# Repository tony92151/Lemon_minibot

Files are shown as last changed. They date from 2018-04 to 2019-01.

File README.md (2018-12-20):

# Lemon minibot

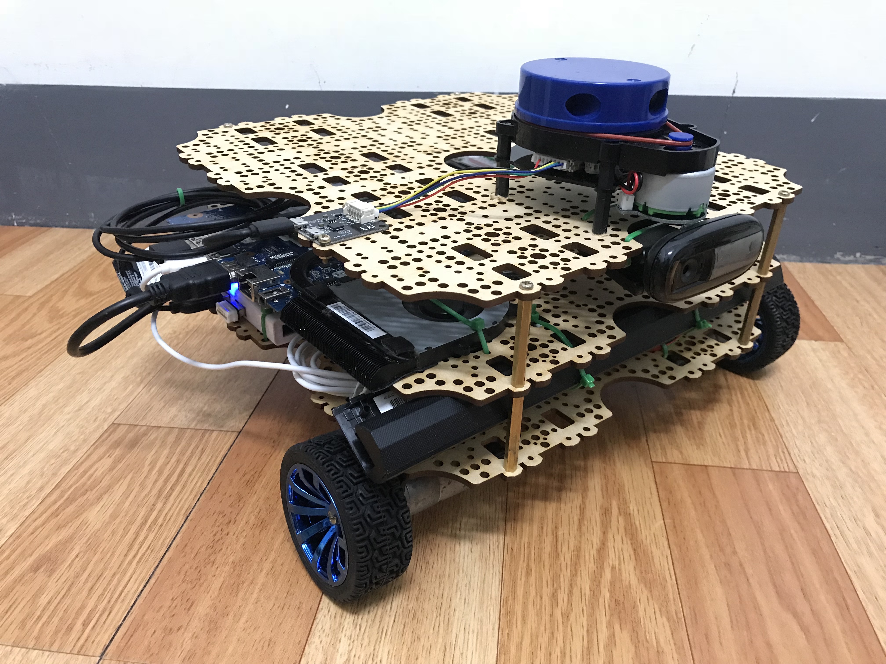
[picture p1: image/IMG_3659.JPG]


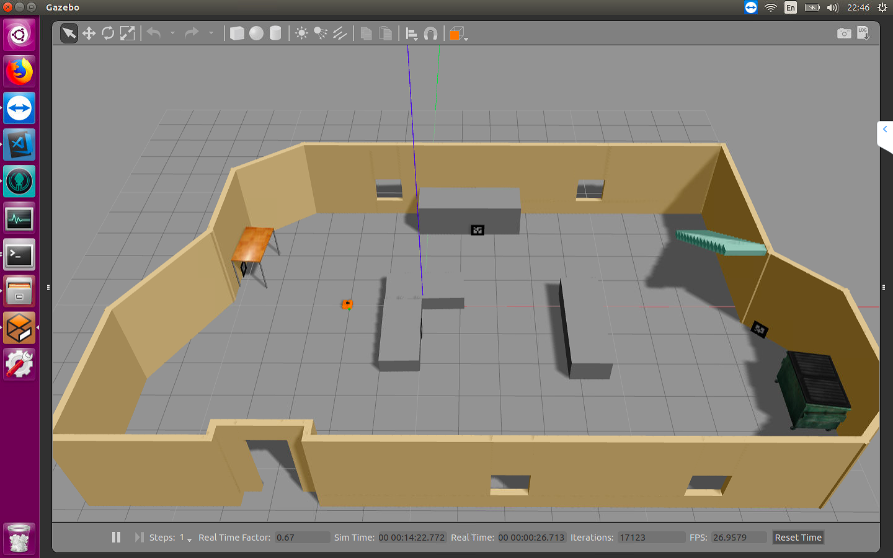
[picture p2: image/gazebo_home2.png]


# Hardware

Raspberry Pi3
(I use the motherboard of lenovo ideapad 100)

YDLidar X4

Arduino mega2560 & motor controller

Motor with A/B encode

14.8v li-po battery

Laser cut frame

# Software

## How to install ROS

Read my medium

https://medium.com/@tony92151/%E5%B0%88%E9%A1%8C%E7%AD%86%E8%A8%98-ros-1-c87bd92b16bc

# How to use

## Clone repositories

1.Clone this repository

> cd catkin_ws/src

> git clone https://github.com/tony92151/Lemon_minibot.git

2.Clone repository for YDLidar X4

> git clone https://github.com/EAIBOT/ydlidar

3.Clone repository for rf2o

> git clone https://github.com/MAPIRlab/rf2o_laser_odometry

4.Clone repository for smach

>git clone https://github.com/ros-visualization/executive_smach_visualization.git

5.instsll dependent

> sudo apt-get install remmina synaptic gimp git ros-kinetic-navigation ros-kinetic-amcl ros-kinetic-slam-gmapping ros-kinetic-mrpt-slam ros-kinetic-mrpt-icp-slam-2d ros-kinetic-robot-localization ros-kinetic-ar-track-alvar -y 

6.Compile all

> cd ..

> catkin_make

## Starup setting

> cd catkin_ws/src/Lemon_minibot/starup/

> sudo chmod +x initenv.sh

then enter your password

>./initenv.sh

## YDLidar X4 starup setting

> roscd ydlidar/starup/

> sudo chmod 777 ./*

> sudo sh initenv.sh

## Add ar-tag models 

> cd

> git clone https://github.com/mikaelarguedas/gazebo_models.git

> cd ar_tags/scripts/

> ./generate_markers_model.py -i ~/Documents/gazebo_models/ar_tags/images -g ~/.gazebo/models -s 80

## Simulation test

> roslaunch turtlebot3_copy turtlebot_world2.launch

If it is first time open gazebo, it will take about 10 min to download models
or you can download manual

See detial here

https://medium.com/@tony92151/%E5%AF%A6%E6%88%B0-ros-gazebo-1-bdb941f184e1

## joystick test (RONEVER SR-012)

> roslaunch joy joy2t.launch

> rostopic echo /car/cmd_vel 

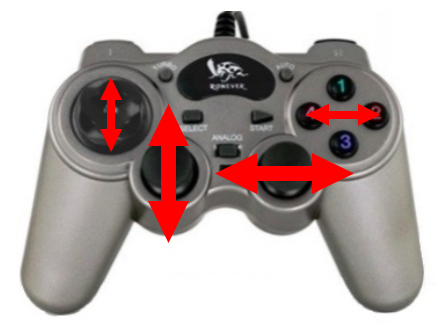
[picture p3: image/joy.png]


### Run gmapping

> roslaunch turtlebot3_copy turtlebot_world2.launch

then gazebo with minibot & home will star

> roslaunch lemon_minibot_detect ar_tag_sim.launch

to save the addres from ar-tag, run tf listener

> rosrun lemon_minibot_core ar_local.py

> roslaunch minibot_simulation simulation_gmapping.launch

to control your robot in gazebo, run keyboard_teleop.py to publish message to control node (/car/cmd_vel)

> rosrun lemon_minibot_control keyboard_teleop.py

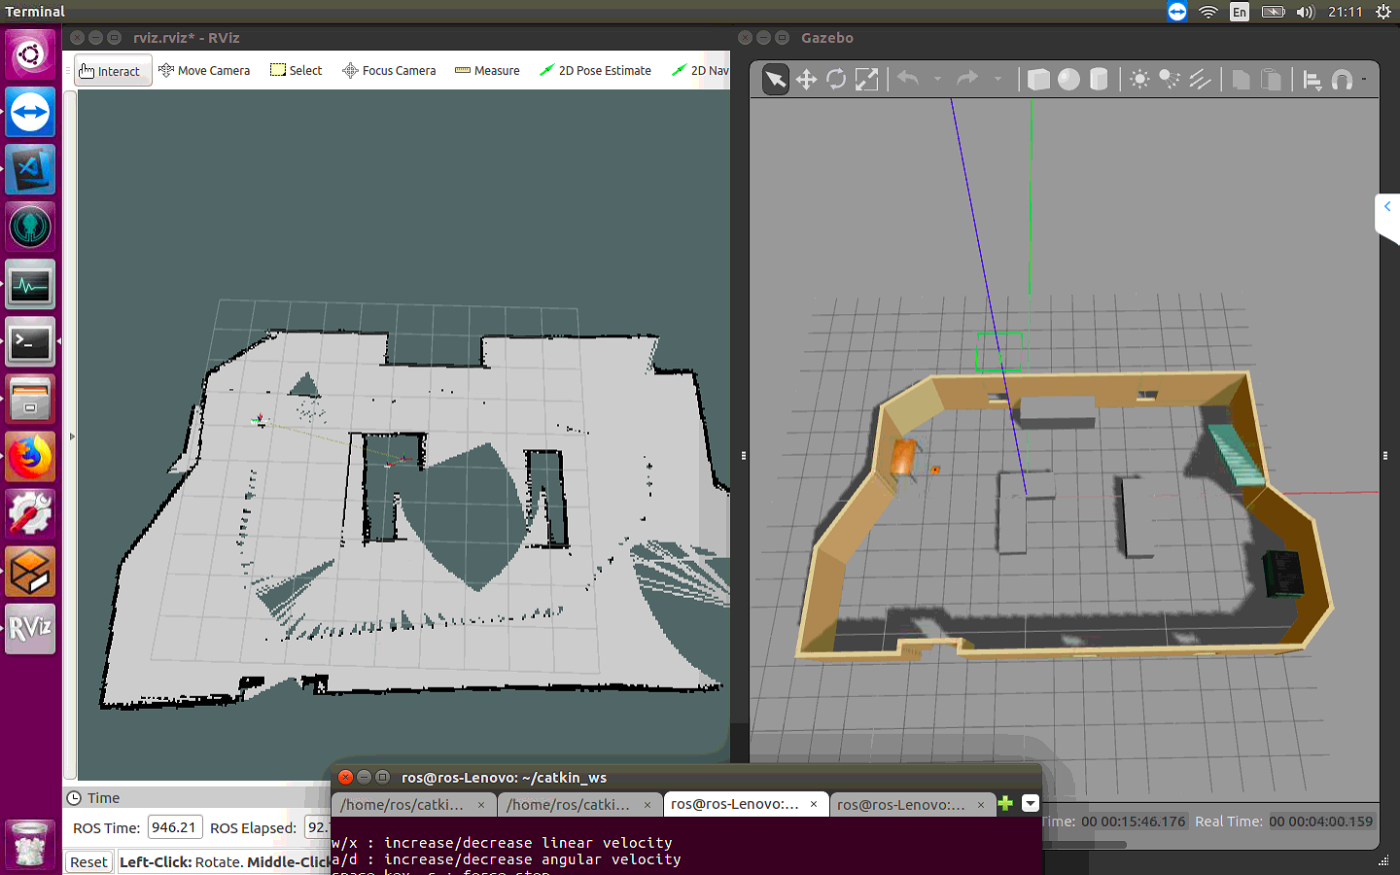
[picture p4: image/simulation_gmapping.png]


When mapping complete, save the map

> rosrun map_server map_saver -f ~/homemap

### run navigation

> roslaunch minibot_simulation simulation_navigation.launch map_file:=$HOME/homemap.yaml

nav goal sender

> roslaunch lemon_minibot_control movebase_seq.launch

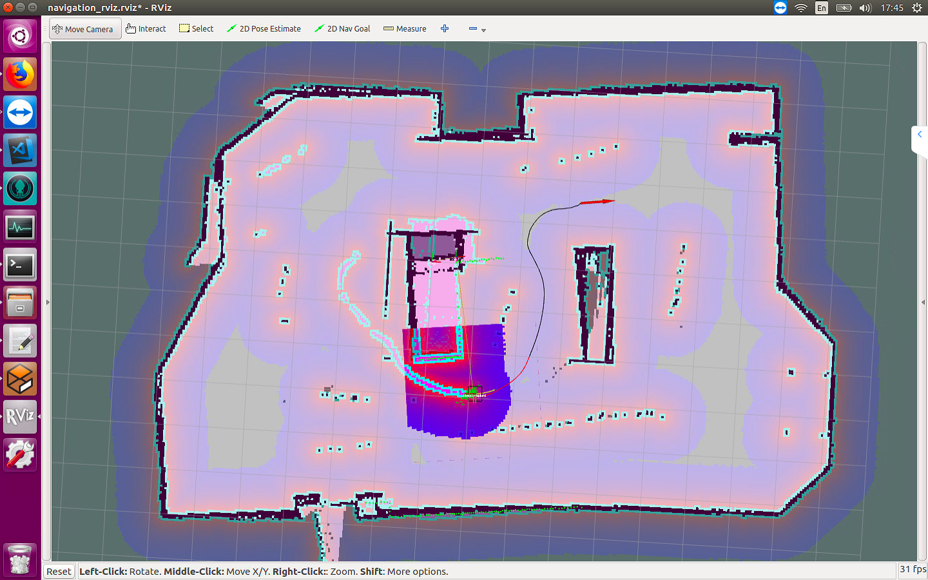
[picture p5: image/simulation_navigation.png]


## Smach viewer 

> rosrun smach_viewer smach_viewer.py

## set up amazom alexa skill

## Use amazon alexa

> rosrun lemon_minibot_core smach3.py

> roscd lemon_minibot_control/scripts/alexa/

> ./ngrok http 5000

and ngrok will give you the address then pastes it to "Alexa skill kit" end point

### install necessary pkg

> sudo apt-get install ngrok-client

> sudo pip install request flask flask-ask requests unidecode

### run web server to connect to amazon alexa skill

> rosrun lemon_minibot_control alexa_skill.py

> roscd lemon_minibot_control/scripts/alexa/

> ./ngrok http 5000

## Demo setup

> roscore

> roslaunch turtlebot3_copy turtlebot_world2.launch

> rosparam load ~/catkin_ws/src/Lemon_minibot/lemon_minibot_core/param/location.yaml

> rosparam load ~/catkin_ws/src/Lemon_minibot/lemon_minibot_core/param/smach.yaml

> rosrun lemon_minibot_core smach3.py

> roscd lemon_minibot_control/scripts/alexa/

> ./ngrok http 5000

> rosrun lemon_minibot_core core_controller.py

# Demo video
(http://www.youtube.com/watch?v=-EDsaaNJGFU "demo")

(http://www.youtube.com/watch?v=rqNOdHbekDU "final")

# Reference

[1]turtlebot3
https://github.com/ROBOTIS-GIT/turtlebot3

[2]gazebo_models
https://github.com/mikaelarguedas/gazebo_models

[3]roslaunch API Usage
http://wiki.ros.org/roslaunch/API%20Usage

[4]Module rosparam in python
http://docs.ros.org/diamondback/api/rosparam/html/

[5]smach Tutorials
http://wiki.ros.org/smach/Tutorials/Getting%20Started

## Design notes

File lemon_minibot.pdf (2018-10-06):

專題研究

# Lemon minibot

# Navigation system robot car

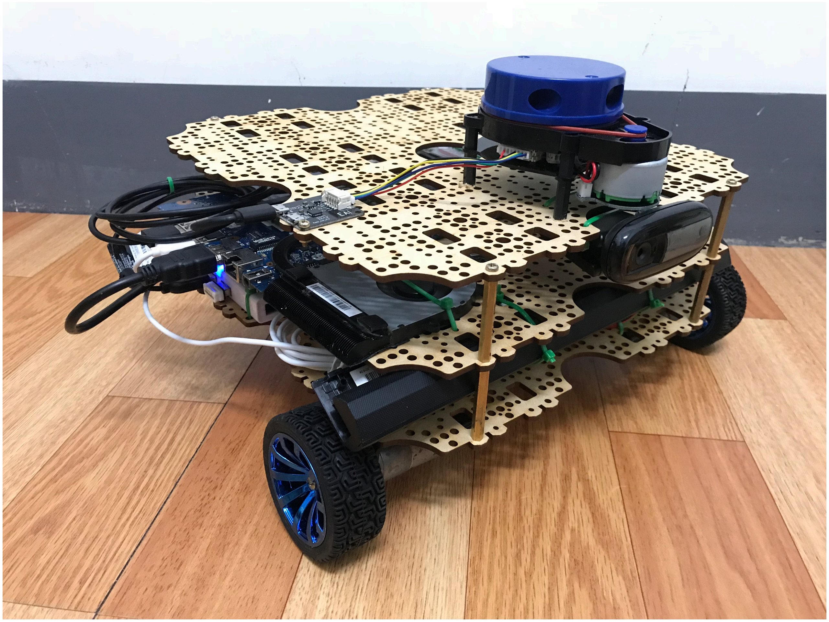
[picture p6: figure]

Authors:Tony Guo

# Abstract

# Content

# Chapter 1 Introduction

# Chapter 2 Hardware

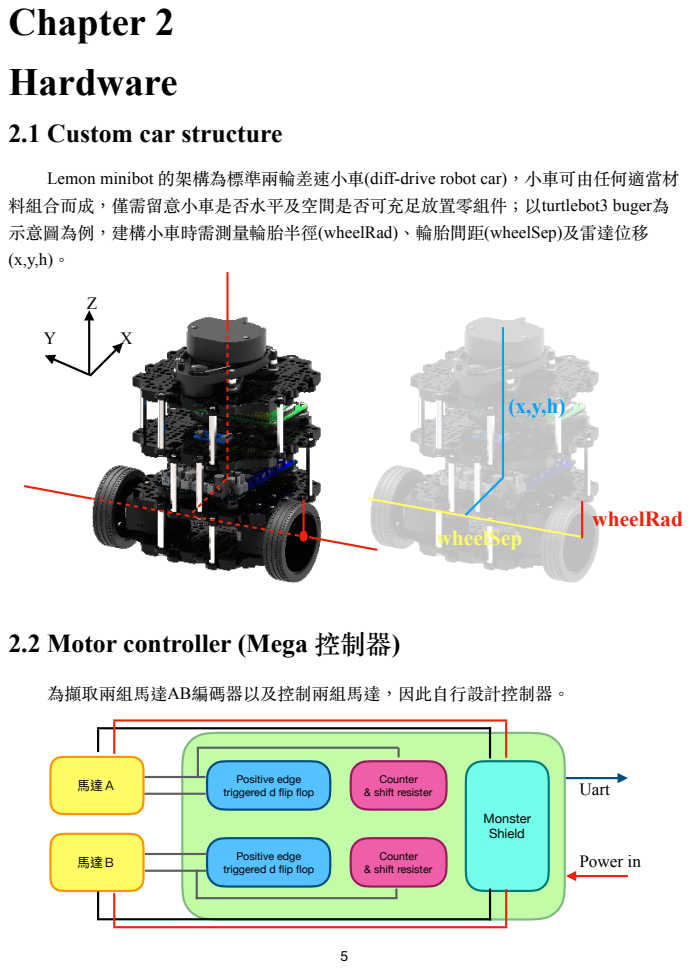
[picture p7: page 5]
wheelSep; wheelRad; ⾺馬達Ａ; ⾺馬達Ｂ; Counter & shift resister; Monster Shield; Uart; Power in

2.1 Custom car structure

Lemon minibot 的架構為標準兩輪差速⼩⾞(diff-drive robot car)，⼩⾞可由任何適當材
料組合⽽成，僅需留意⼩⾞是否⽔平及空間是否可充⾜放置零組件︔以turtlebot3 buger為
⽰意圖為例，建構⼩⾞時需測量輪胎半徑(wheelRad)、輪胎間距(wheelSep)及雷達位移

2.2 Motor controller (Mega 控制器)

為擷取兩組⾺達AB編碼器以及控制兩組⾺達，因此⾃⾏設計控制器。

Positive edge
triggered d flip flop

### 2.2.1 Motor & A/B encoder

擁有AB增量型編碼器的⾺達都有6pin，分別為⾺達正負極、編碼器電源以及AB相輸 出，接下來將說明如何使⽤編碼器訊號測量轉向以及轉速，在這之前也必須先知道⾺達的 PPR (Pulses per rev)值，意味著轉⼀圈會經過幾個脈衝︔再者如果⾺達有經過減速機，則 須將PPR乘上減速比。

Lemon minibot 所使⽤的的編碼器為AB增量型編碼器，編碼器輸出為AB相，如下 圖，A與B之間相位差為90度。

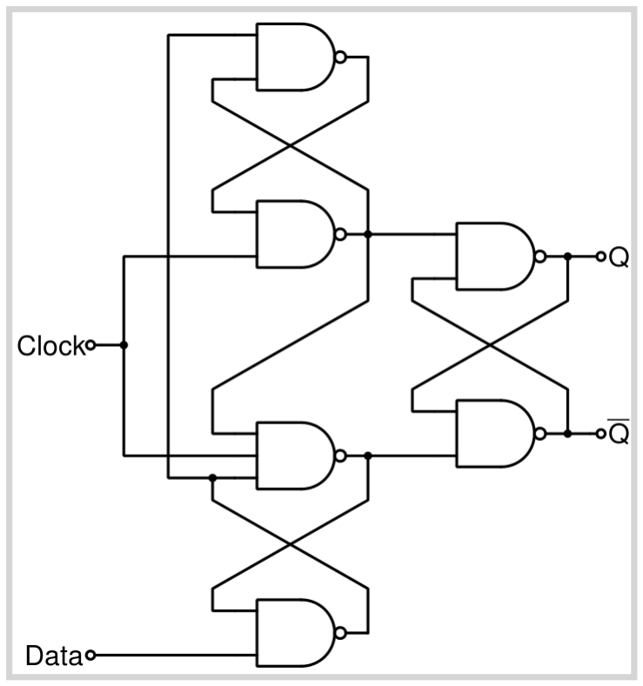
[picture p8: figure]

### 2.2.2 Positive edge triggered d flip flop

正緣觸發D正反器 (positive edge triggered d flip flop)，可以將AB相轉換成單⼀輸出的轉向︔當clock背A 相正緣觸發時會將Q輸出B相的值，⽽依照2.2.1 AB相圖 可知，正反轉會輸出不同的值，並以此作為正反轉訊號。

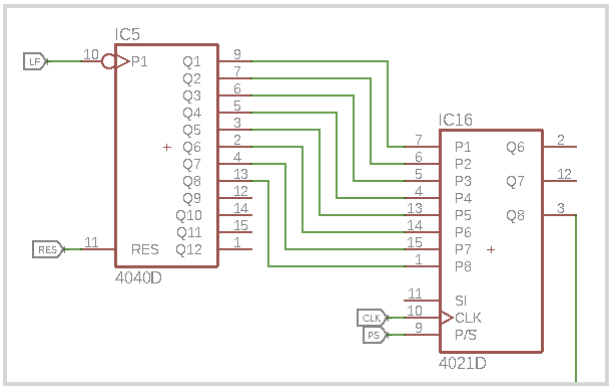
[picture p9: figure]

### 2.2.3 Counter & shift resister

CD4040為12bits計數器 (Counter)， CD4021為8bits的位移暫存器 (Shift
resister)︔解釋期運作原理，將訊號由計數
器的PIN10輸入，輸入脈衝數換成⼆進位
制由Q1~Q12輸出，再經過位移暫存器輸
入至微控器。

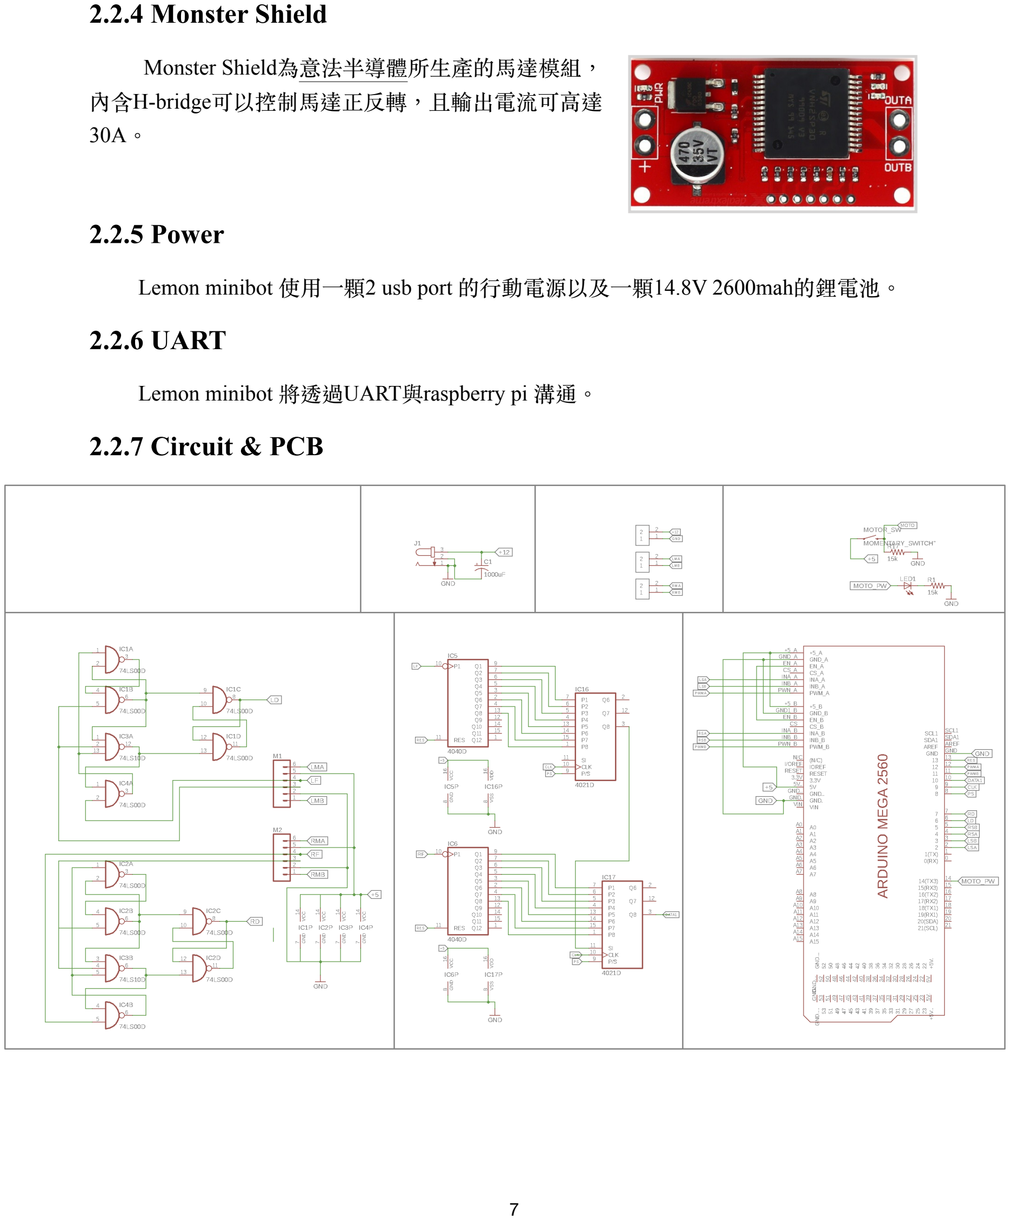
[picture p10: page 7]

### 2.2.4 Monster Shield

Monster Shield為意法半導體所⽣產的⾺達模組， 內含H-bridge可以控制⾺達正反轉，且輸出電流可⾼達
30A。

### 2.2.5 Power

Lemon minibot 使⽤⼀顆2 usb port 的⾏動電源以及⼀顆14.8V 2600mah的鋰電池。

### 2.2.6 UART

Lemon minibot 將透過UART與raspberry pi 溝通。

### 2.2.7 Circuit & PCB

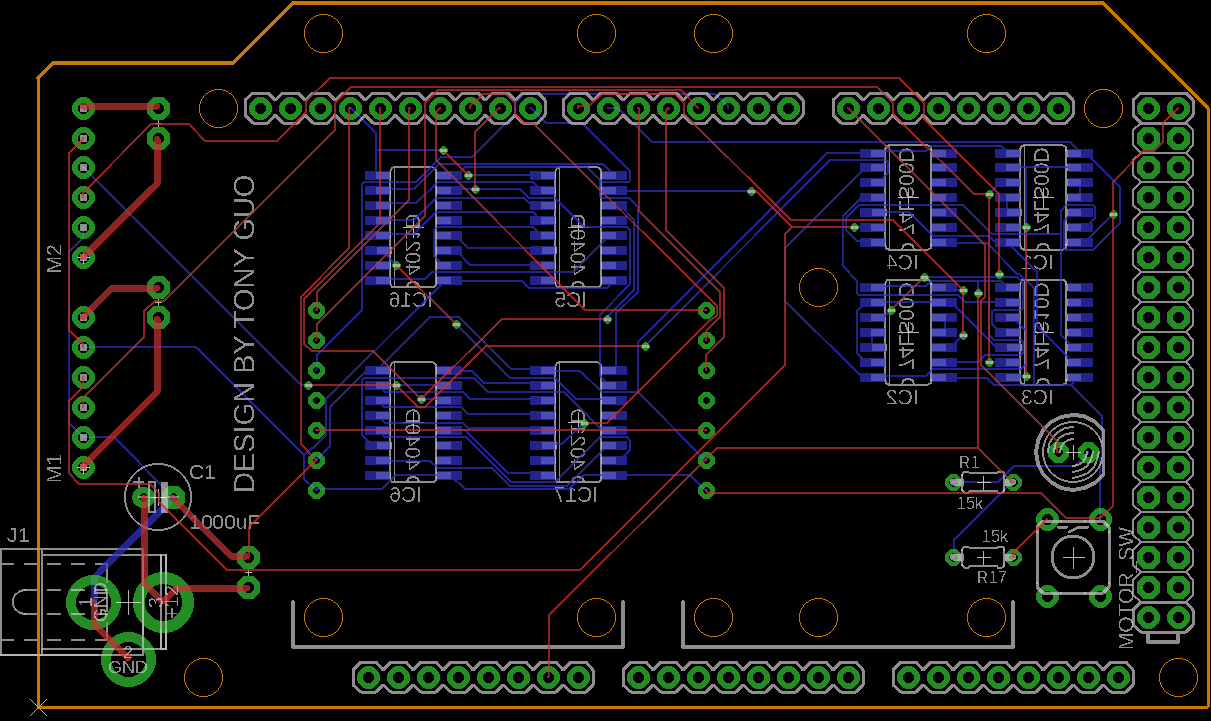
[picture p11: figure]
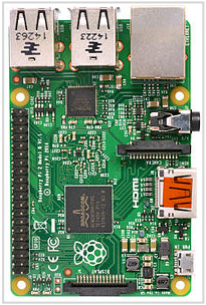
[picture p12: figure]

### 2.3 Raspberry pi 2/3

Lemon minibot 使⽤raspberry pi 當作主控器，運⾏ ubuntu mate 16.04 與 ROS (機器⼈作業系統) 以⽤來控制與接 收 (電腦端)訊號。

電腦端及pi端安裝⽅式，請參考<專題筆記：ROS #1 安 裝>，電腦端及pi端安裝⽅式相同，但是pi若沒有接上螢幕， (https://medium.com/@tony92151/%E5%B0%88%E9%A1%8C%E7%AD%86%E8%A8%98-ros-1-c87bd92b16bc) 則Open GL 將不會被開啟⽽導致無法使⽤ VNC開啟 GUI介 ⾯。

### 2.4 YDLIDAR X4

Lemon minibot 使⽤EAI的ydlidar X4光達來 建置2D地圖︔因為其消耗功率⼤，除了通訊USB
接⼜外，必須另外連接⾏動電源供電。

# Chapter 3 Concept

### 3.1 Transform (TF)

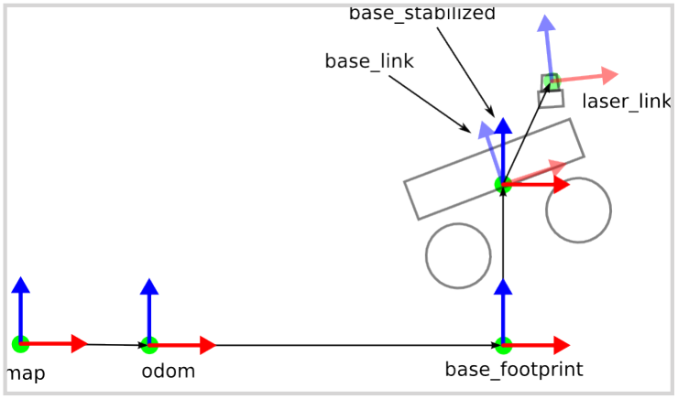
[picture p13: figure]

為記載各個裝置位置，使⽤TF可以設置其
相關位置。

Map : 固定的地圖

Odom : 移動路徑

Base_link : 由sensor推算之座標

Base_footprint : Base_link 之投影

Laser_link : 光達位置

### 3.2 Pose & Odometry

### 3.2.1 Orientation 四元數

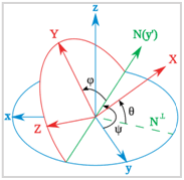
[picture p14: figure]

欲表現三空間的鋼體運動，常⾒的有歐拉角與四元數，
其中歐拉角具有奇異性(例：Gimbal lock problem)，可想⽽ 知，若只使⽤三個變數表⽰三維運動，可能有多種不同的運動 ⽅式產⽣相同結果︔因此使⽤具有四個變數的“四元數”來表⽰ 其運動較為恰當，且也具有歐拉角與四元數之間的轉換公式。 右圖為歐拉角⽰意圖。

四元數表⽰法如下：

四元數為⼀位實數以及三位虛數所構成，滿⾜

q = q0 + q1i + q2 j + q3k

i

2 = j

2 = k²
ij = k, ji = − k
jk = i, k j = − i
ki = j, ik = − j

也可使⽤⼀個純量及⼀個向量表⽰

假設某個旋轉是繞著單位向量 | 進⾏旋轉 角，那麼以四元數表⽰為
接下來欲把空間⼀點 | 經過 做旋轉，則新座標 等於
| 化成

則R為

### 3.2.2 EKF

### 3.3 Kinematic model

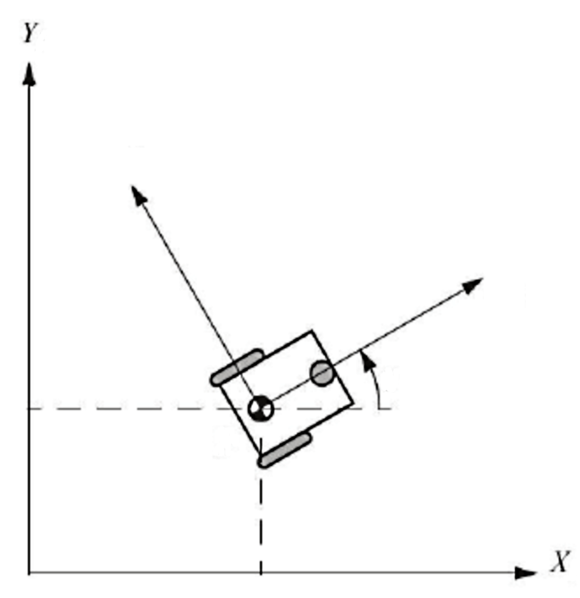
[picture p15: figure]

設左輪角速度 、右輪角速度 ，則速度如下

### q = [s v],s = qo ∈ ℝ, v = [q1 q2 q3] T ∈ ℝ³

n = [

nx ny nz]
T | Θ

### q = [cos( Θ 2 ) nx sin( Θ

### 2 ) ny sin( Θ

### 2 ) nz sin( Θ

2 )

]

p = [x y z] ∈ ℝ³ | q | p′
p′ = qpq⁻¹ | p′ = Rp

R =

1 − 2q²

2 − 2q²
3 2q1q2 − 2q0q3 2q1q3 + 2q0q2

### 2q1q2 + 2q0q3 1 − 2q²

1 − 2q²
3 2q2q3 − 2q0q1

### 2q1q3 − 2q0q2 2q2q3 − 2q0q1 1 − 2q²

1 − 2q²
2
ωl | ωr
{
| vl = wheelRad *ωl vr = wheelRad *ωr

V = vr + vl
| 2 = wheelRad *

ω·

r + ω·
l
2
| α = vr − vl wheelSep
{

### Vx = V cos α Vy = V sin α

{

| X = X + Vx

* dt
| Y = Y + Vy

* dt

# Chapter 4 Package

### 4.1 Base.py

透過Uart 連接Mega 控制器，傳送⾺達控制訊號以及接收⾺達轉速訊號，並積分轉換成
odom

Node : /base

Subscribe : /car/cmd_vel

Publish : /tf , /odom

### 4.2 keyboard_teleop.py

透過鍵盤傳送速度訊號

Node : /teleop

Publish : /car/cmd_vel

### 4.3 Joystick

使⽤遊戲搖桿

Node : /joy

Publish : /joy

### 4.5 teleop_joy.cpp

遊戲搖桿轉換成控制訊號

Node : /teleop

Subscribe : /joy

Publish : /car/cmd_vel

### 4.4 YDLIDAR X4

連接YDLIDAR X4並輸出雷射掃描資訊

Node : /ydlidar_node

Publish : /scan

### 4.5 TF

設定座標轉換

### 4.6 rf2o

將雷射掃描資訊轉換成⾥程計odometry

Node : /rf2o_laser_odometry

Subscribe : /laser_scan

Publish : /odom

### 4.7 robot pose ekf

使⽤EKF融合

Node : /rf2o_laser_odometry

Subscribe : /odom , /imu_data , /vo

Publish : /robot_pose_ekf/odom_combined

### 4.8 ar track alvar

### 4.9 Gmapping

# Chapter 5 Control Mode Flow

### 5.1 Locate Ar-Tag & SLAM

### 5.2 Goal sitting through speaker recognition

Sensor | Detect | Control | Algorithm | Core
Camara | Ar tag
Detector

Motor
| | Controller | Gmapping

Core

Laser lidar Speaker
recognition

Ramdom

Walk

Navigation

Sensor | Detect | Control | Algorithm | Core
Camara | Ar tag
Detector

Motor
| | Controller | Gmapping

Core

Laser lidar Speaker
recognition

Random

Walk

Navigation

# Chapter 6 Build guide

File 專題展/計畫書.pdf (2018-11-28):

## 107學年度「機電實作專題成果展」

## 構想書

## 智慧導盲犬機器人

## Guide Dog Robot

### 國立中山大學/ 機械與機電工程學系/ 郭俊志/

B 043021050

### 指導教授：潘正堂

### 主辦單位：國立中山大學機械與機電工程學系

一、摘要

本計畫開發智慧導盲犬機器人 (簡稱：機器犬)，應用於先天或後天的因素，導致身 體上的缺陷的人類，改善行動的不便。在視障人士中，現今社會仍是以導盲犬來引導人 類的行動，若能使用機器來取代動物，將會節省許多成本。在本計畫中，機器犬搭載語 音助理系統(Amazon Alexa)以提供機器犬目標地點資訊，再藉由影像辨識 (OpenCV)，進 一步達到即時避障功能。再以微控制器(Atmel AVR) 控制輪胎移動以實現導航，最後以 機器人作業系統 (Robot OperatingSystem, ROS) 整合所有功能，做出全國第一台 ROS 系 統建立之智慧輔助導盲型機器人。

二、動機與目的

近年來隨著電腦科學快速發展，已經有不少產品應用深度學習系統來取代人類的工 作，但在現實生活中，能為視障者導盲的方式目前只有導盲犬，但因為動物本身具有不 穩定性，可能會因為外界的因素與誘惑，導致其本身沒有遵守視障者的命令，可能導致 意外的發生，所以本計畫提出利用機器犬來取代一般的導盲犬，其機器的準確性與多功 能配備能夠更完整的提供視障者安全的指引道路與危險提醒。

三、研究內容

本計畫應用到許多不同套件進行整合，透過 ROS 當作各資料點之間溝通的橋樑，其 主要功能為

l 2D SLAM

應用雷射雷達，在電腦中建置地圖，當作世界座標，並在其世界座標上標示地點位 置，另外也可以使用雷射雷達之特徵，計算出裝置(車體)位移路徑，使的裝置除了 使用編碼器計算位置，還能融合雷射雷達之特徵使之能夠更加準確。
l Navigation
應用蒙特卡羅定位法(Particle Filter Localization)，定位出自己的位置之後，在使用 Trajectory Rollout 算法找出路徑並執行。

l AR recognition

應用成熟的 AR 技術，可使用單鏡頭將空間中的 AR-tag 定位到世界座標上，並儲存 以供後續導航需求。
l Audio Assistant

使用技術已成熟之 Amazon Alexa 作為基底，不僅能提供生活日常資訊，也可以用 來控制機器犬，應用極為廣泛。

結合以上功能，為求整合方便，將其硬體輸入以及其演算法，分開成數個功能包， 分別使用狀態機觸發，達到整合效果。

四、結果與討論

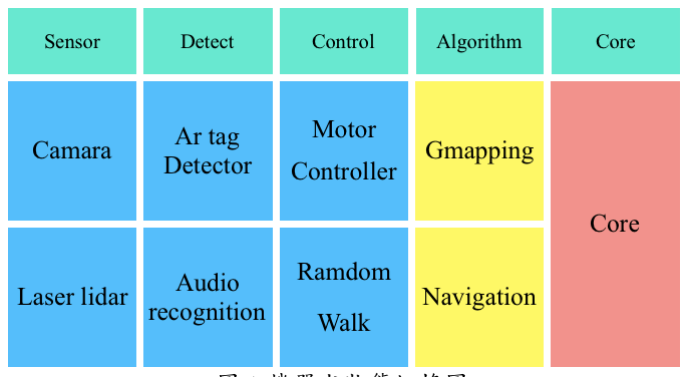
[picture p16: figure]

使用目前用有的技術已經足夠完成此項作品，其成本分析如下

名稱 | 數量 | 價格
工業電腦 | 1 | 8000
雷射雷達 | 1 | 3000
馬達 | 2 | 500
攝影機 | 1 | 600
Echo dot | 1 | 1200
鋰電池 | 1 | 1000
馬達控制器 | 1 | 500
訂製框架 | 1 | 500

其陳本非常低廉，且模組化零件適合大量生產，具有易維修，易更新使得產品功能 更加強大。在可預期的未來，硬體成本將會降低，使得軟體更具備發展優勢。

圖 1 機器犬狀態切換圖

五、相關剪影

六、致謝

感謝前組員，吳力恩、滕景平、李宗澤、實驗室學長姐以及潘老師。

七、參考文獻

[1] OLAMI 人工智慧開放平台/快速指南，OLAMI 文件中心，2017
[2] Christian Szegedy, Vincent Vanhoucke, Sergey Ioffe, Jon Shlens, Zbigniew Wojna, “Rethinking the Inception Architecture for Computer Vision,” arXiv.org, 2016.
[3] Tom Hope, Yehezkel S. Resheff, Itay Lieder, “Learning TensorFlow: A Guide to Building Deep Learning Systems”, 2017.
[4] 趙英傑，超圖解 Arduino 互動設計入門（第二版），旗標科技，2014
[5] Howie Choset, Kevin Lynch, Seth Hutchinson, George Kantor, Wolfram Burgard, Lydia Kavraki, and Sebastian Thrun, “Principles of Robot Motion: Theory,Algorithms, and Implementation,” 2007.
[6] Rosen Diankov, “Automated Construction of Robotic Manipulation Programs,”

Carnegie Mellon University, 2010.

[7] Carol Fairchild，Dr. Thomas L. Harman, “ROS Robotics By Example”, 2016.

Lentin Joseph, “ROS Robotics Projects”, 2016

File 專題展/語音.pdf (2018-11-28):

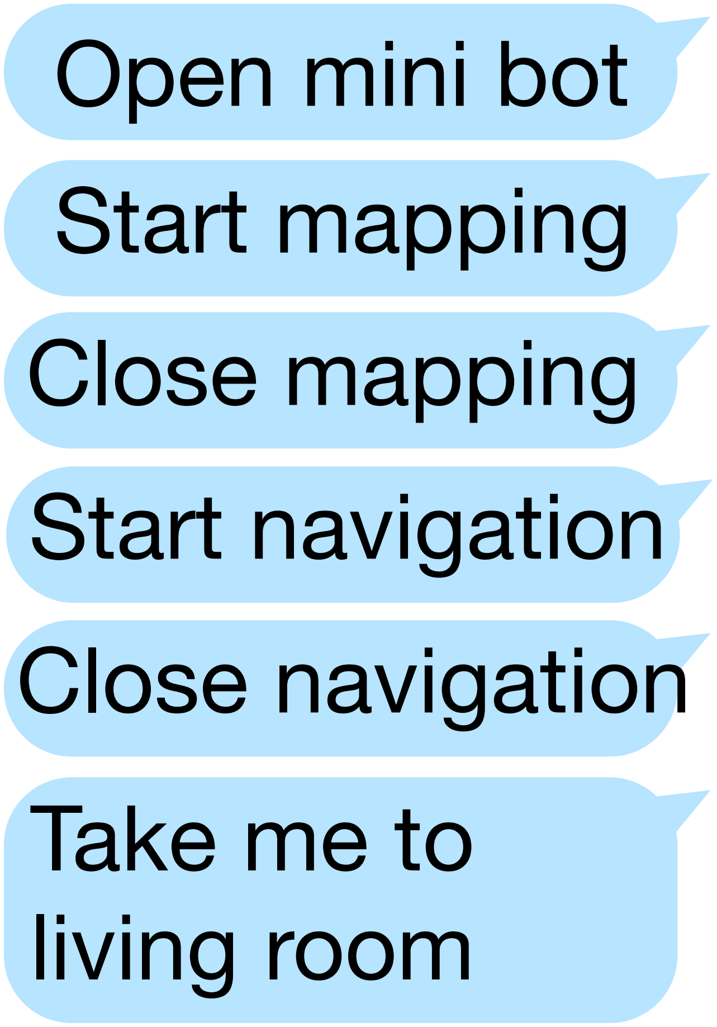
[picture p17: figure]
Open mini bot Start mapping Close mapping Start navigation Close navigation Take me to living room

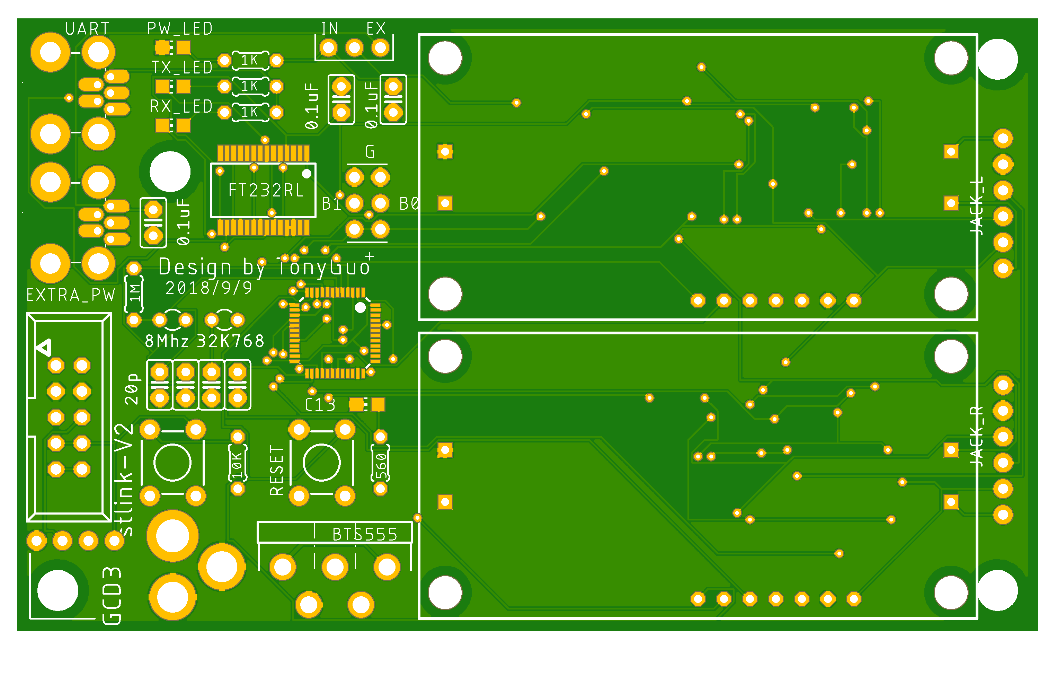
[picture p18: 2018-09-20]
hardware/PCB/stm32/motor_counter7_UP.png

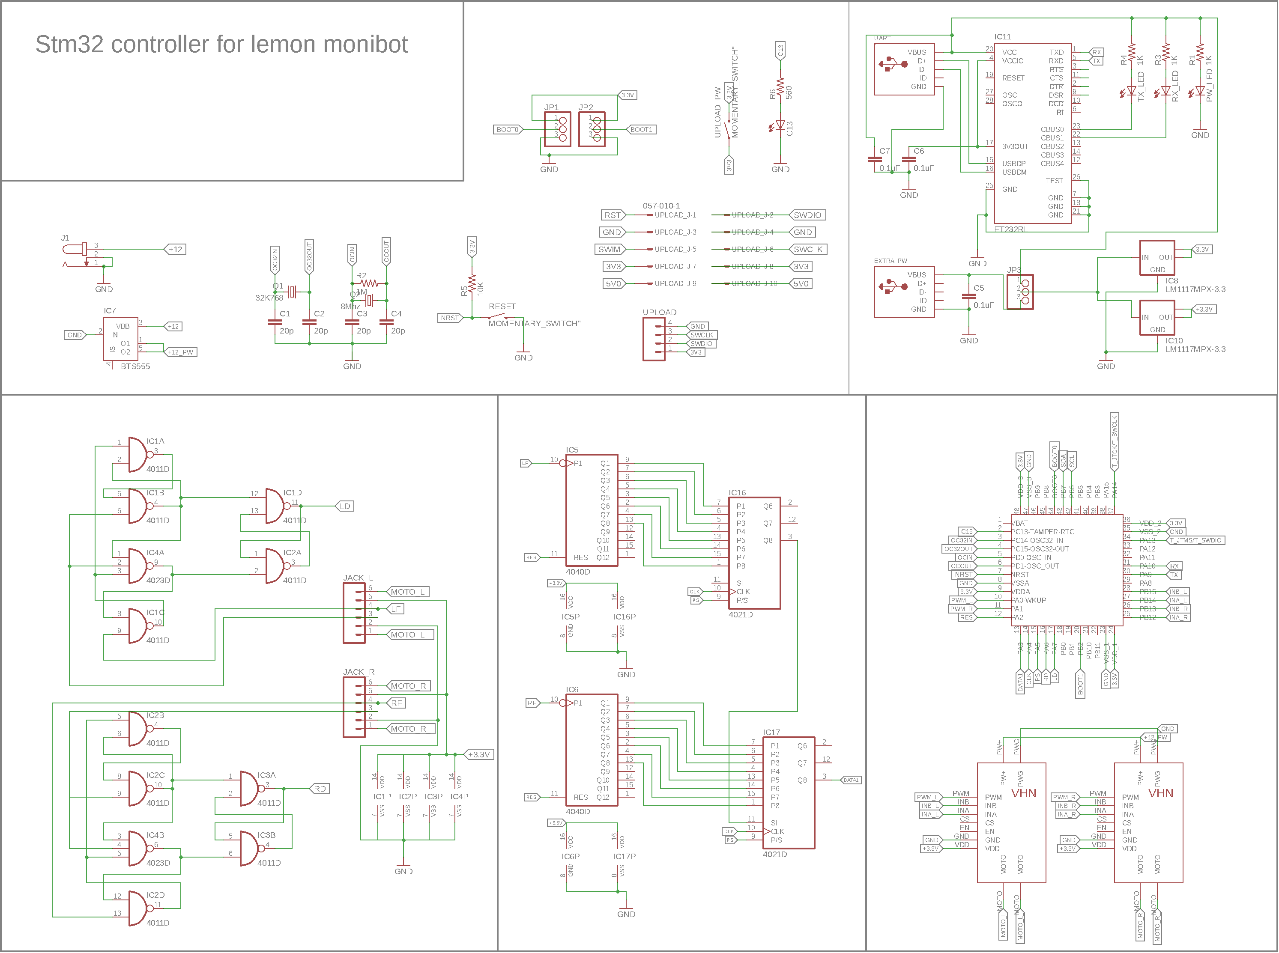
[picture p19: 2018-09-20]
hardware/PCB/stm32/stm32.png

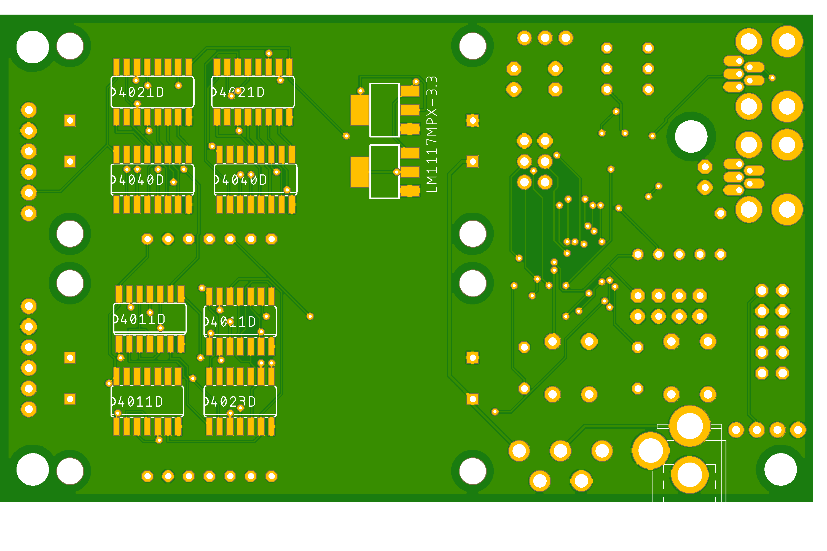
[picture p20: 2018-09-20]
hardware/PCB/stm32/motor_counter7_DOWN.png

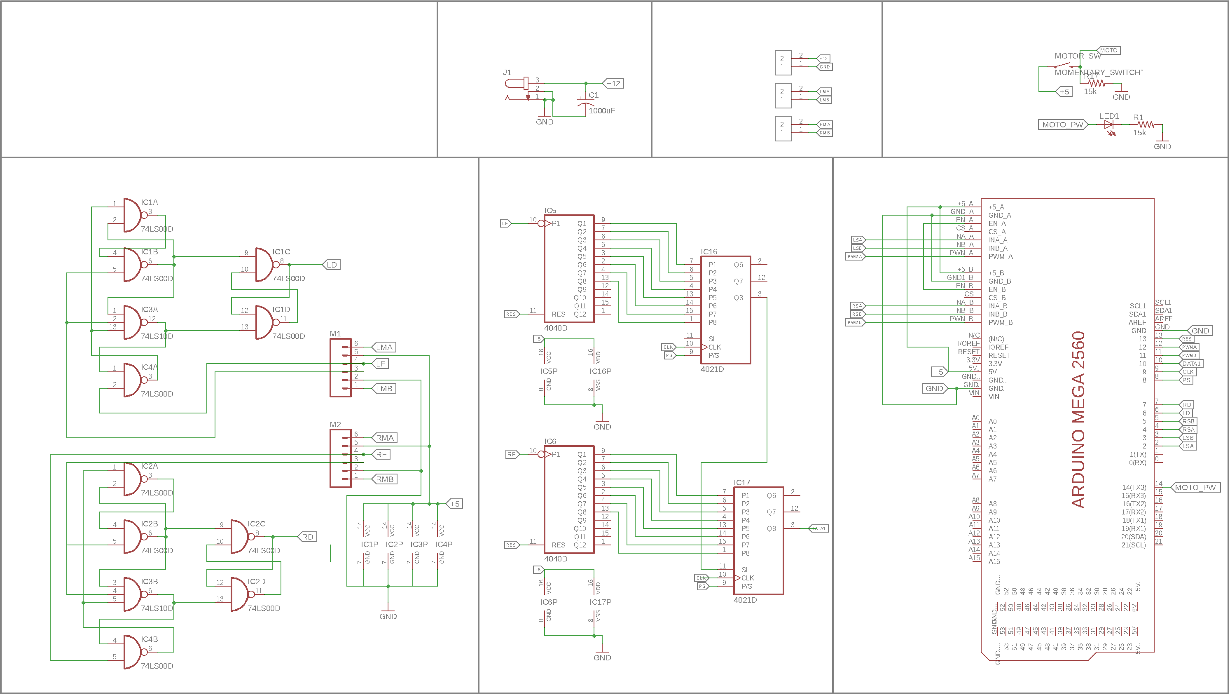
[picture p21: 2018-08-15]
hardware/PCB/mega2560/circuit.png

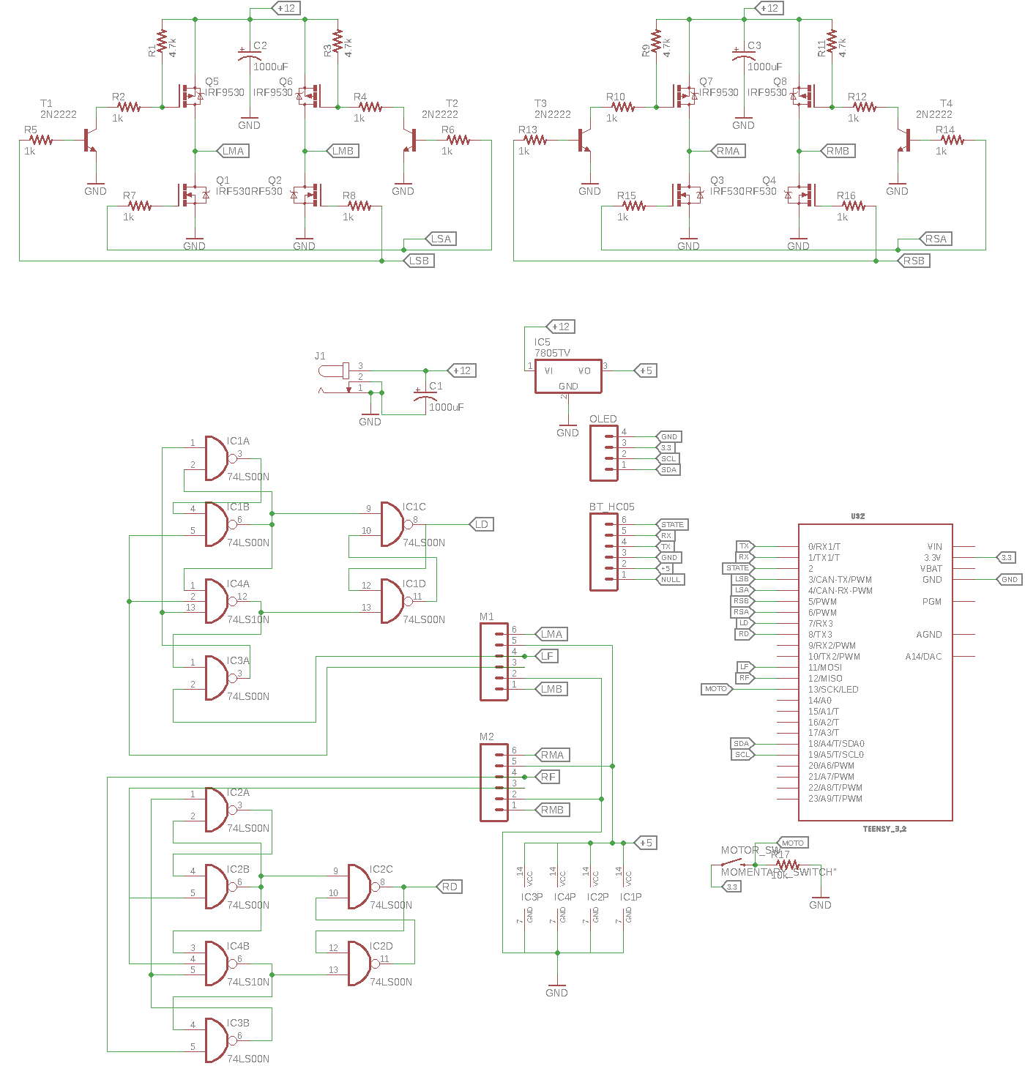
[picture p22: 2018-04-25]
hardware/PCB/teensy3.2/circuit.png

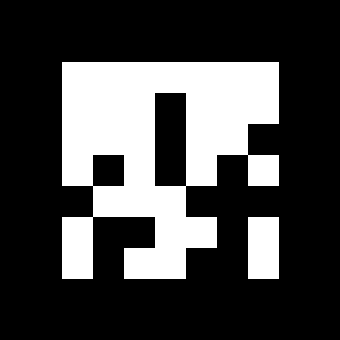
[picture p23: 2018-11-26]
image/ar_image/MarkerData_1234.png

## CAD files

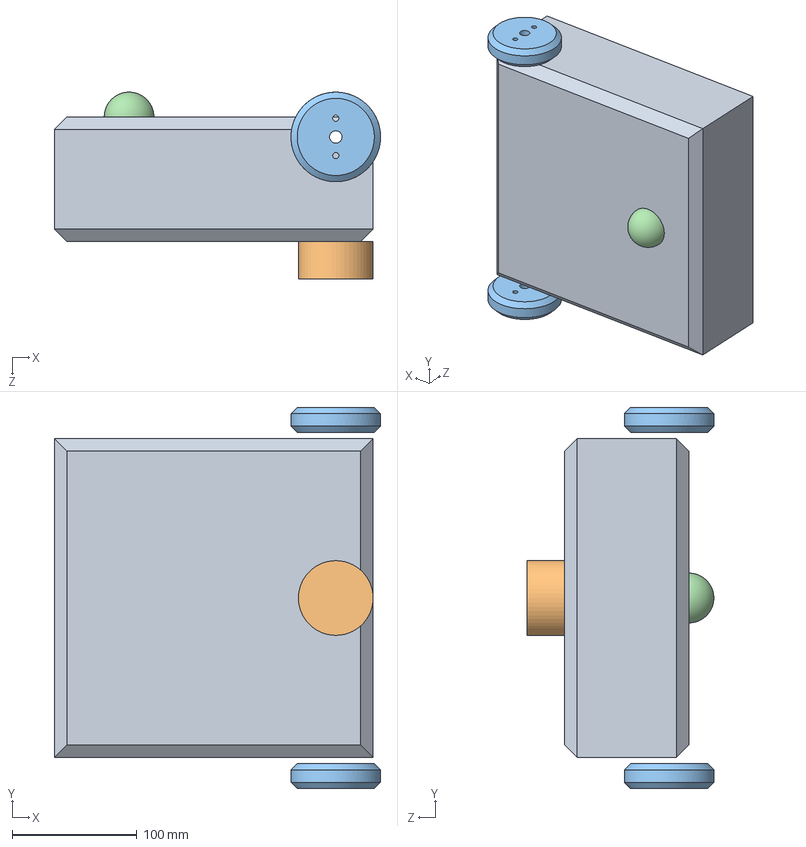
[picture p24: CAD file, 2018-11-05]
gazebo/sw2016/minibot.SLDASM
262.0 x 306.0 x 150.0 mm
base
laser
wheel x 2
cir

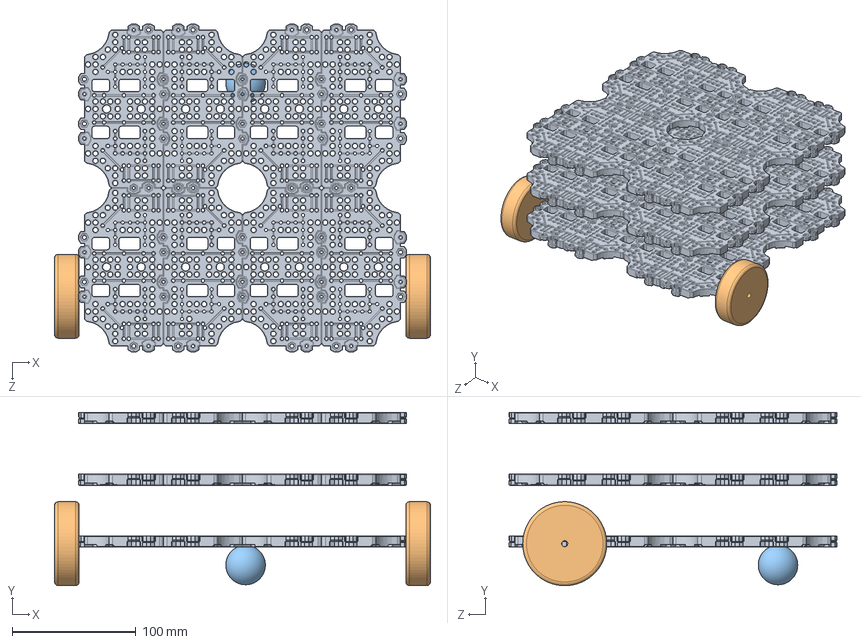
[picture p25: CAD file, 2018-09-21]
hardware/solidworks2018/minibot.SLDASM
304.3 x 140.2 x 265.5 mm
waffle_plate - P-BP-A001_3D x 24
wheel x 2
wheel2

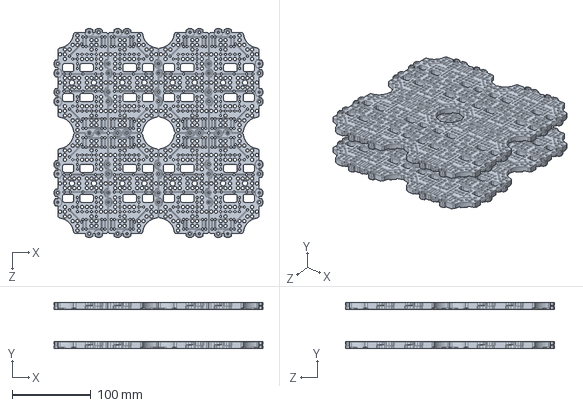
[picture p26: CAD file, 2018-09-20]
hardware/solidworks2018/layer.SLDASM
265.5 x 59.0 x 265.5 mm
waffle_plate - P-BP-A001_3D x 16

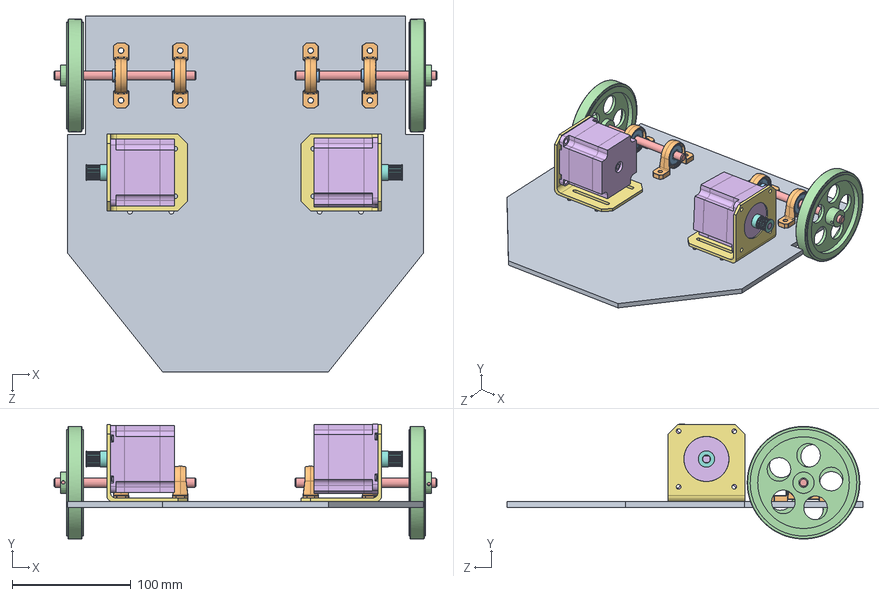
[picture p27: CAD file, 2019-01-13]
hardware/sw2016/assm.SLDASM
323.2 x 97.0 x 300.0 mm
base
KP08_1 x 4
608RS x 4
wheel_95mm x 2
8mm_rod_150mm x 2
57motor x 2
mount nema 23 x 2
gt2_20th x 2

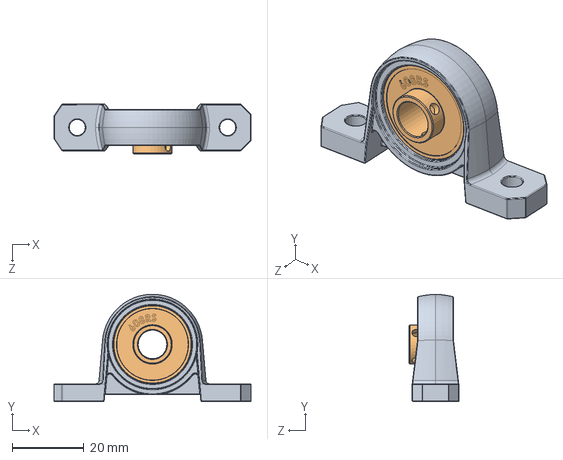
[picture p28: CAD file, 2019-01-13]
hardware/sw2016/KP081.SLDASM
55.0 x 30.0 x 13.9 mm
KP08_1
608RS

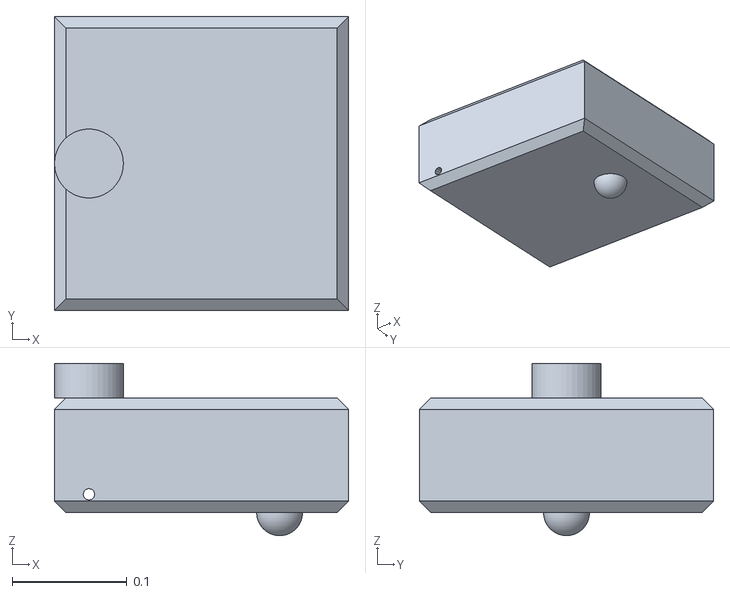
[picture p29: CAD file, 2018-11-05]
gazebo/minibot_simulation/meshes/base_link.STL
0.256 x 0.256 x 0.15

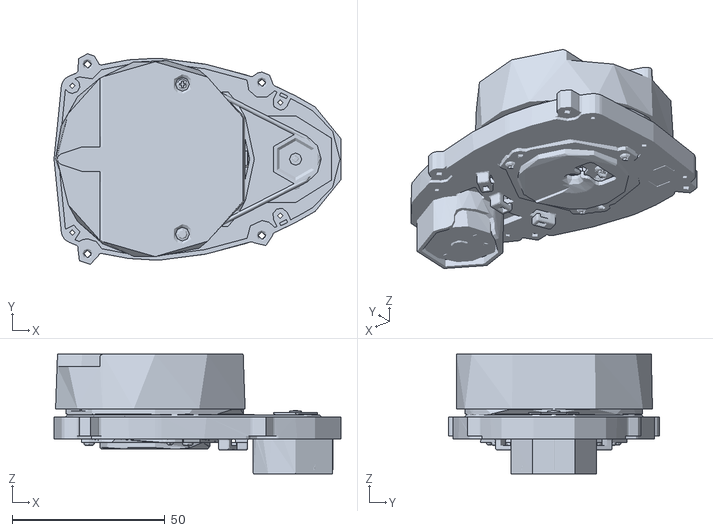
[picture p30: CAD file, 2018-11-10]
gazebo/turtlebot3_copy/meshes/sensors/lds.stl
93.8 x 68.9 x 39.2

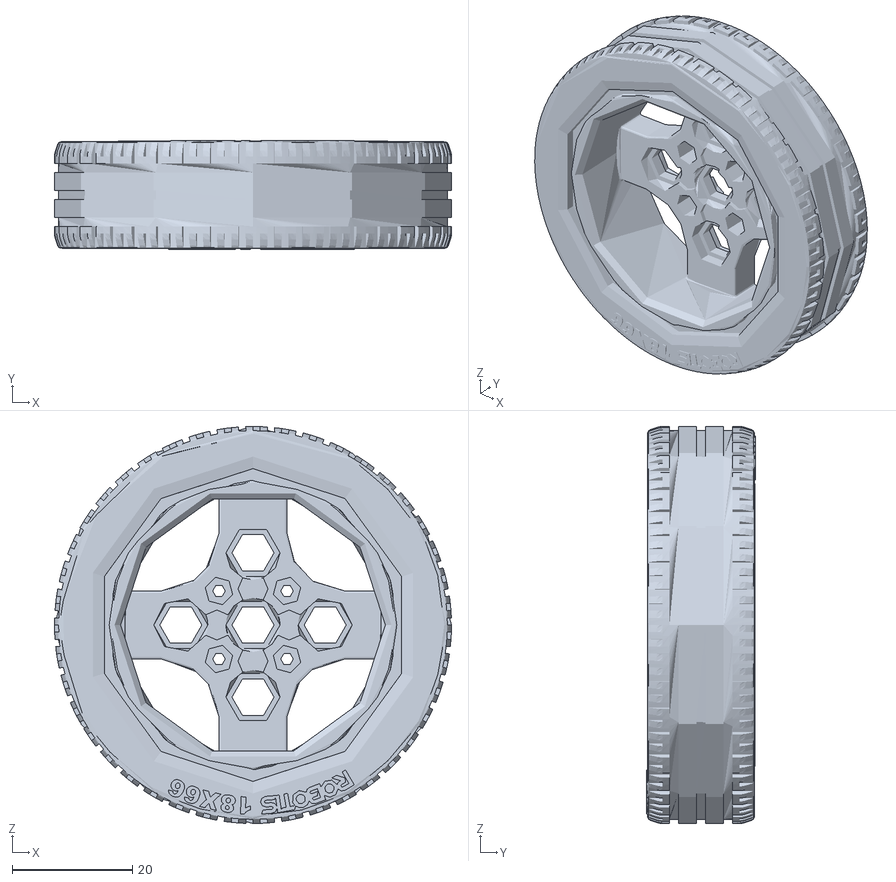
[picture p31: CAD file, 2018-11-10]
gazebo/turtlebot3_copy/meshes/wheels/right_tire.stl
66.0 x 18.2 x 66.0

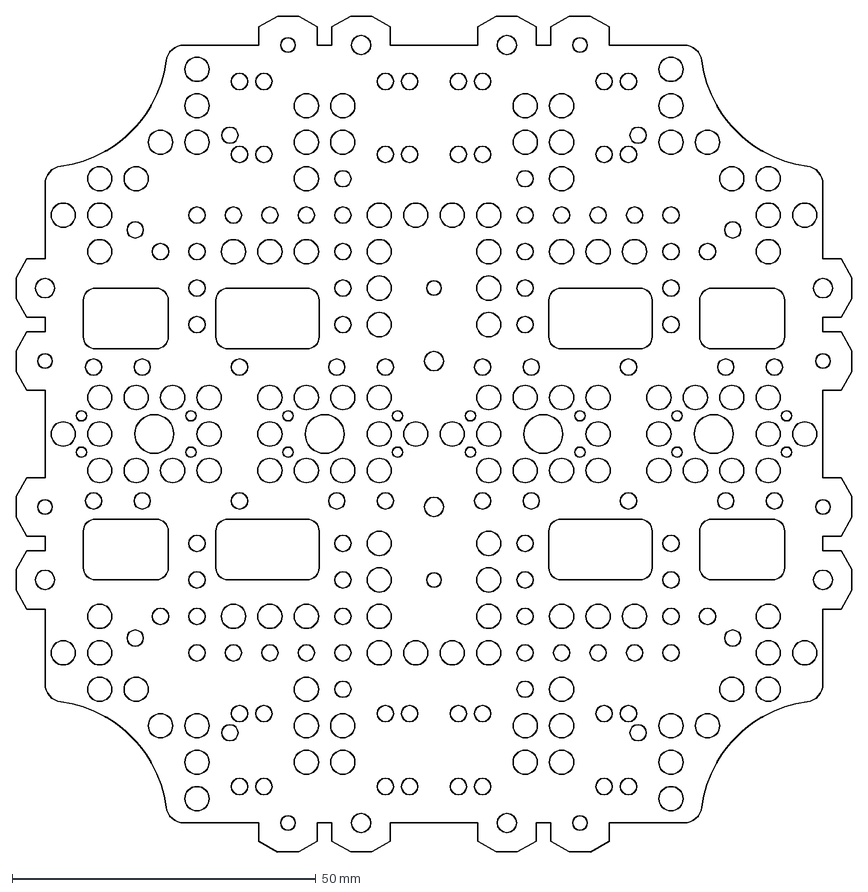
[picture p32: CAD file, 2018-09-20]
hardware/laser cut frame/waffle_plate_burger.dxf
137.5 x 137.5 mm

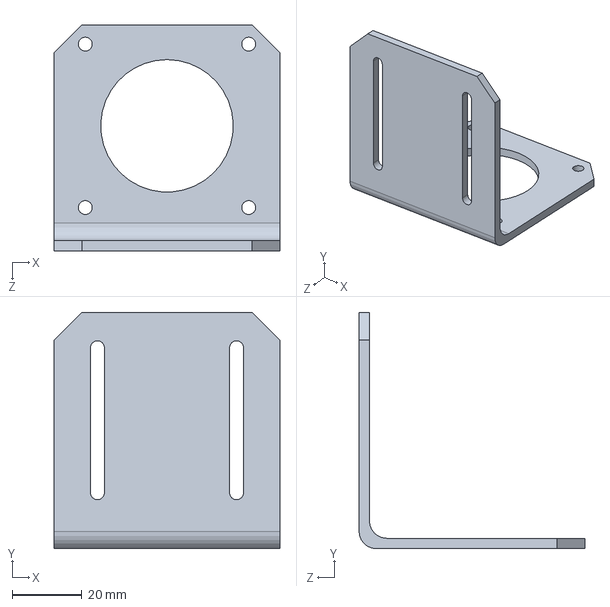
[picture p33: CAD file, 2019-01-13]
hardware/sw2016/mount nema 23.SLDPRT
65.0 x 68.0 x 65.0 mm

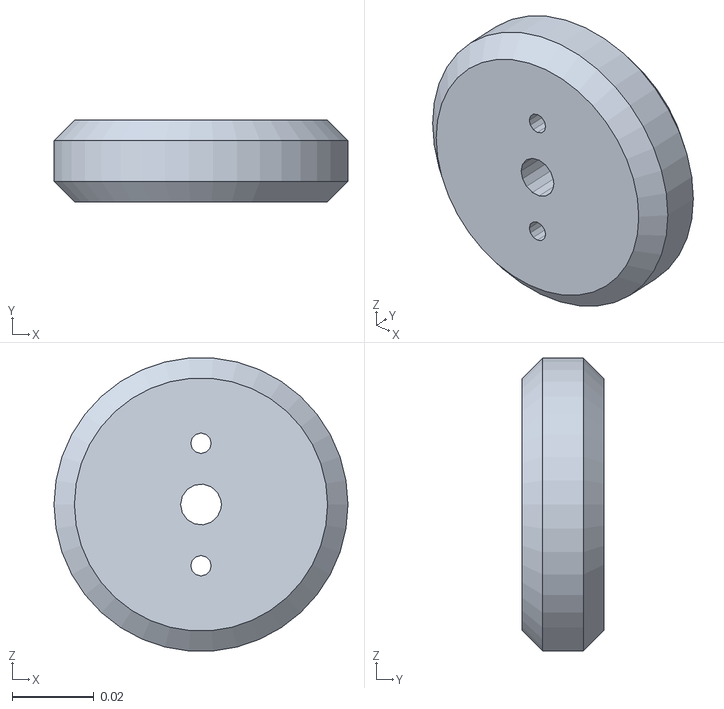
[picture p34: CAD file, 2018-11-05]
gazebo/minibot_simulation/meshes/r_wh.STL
0.072 x 0.02 x 0.0718

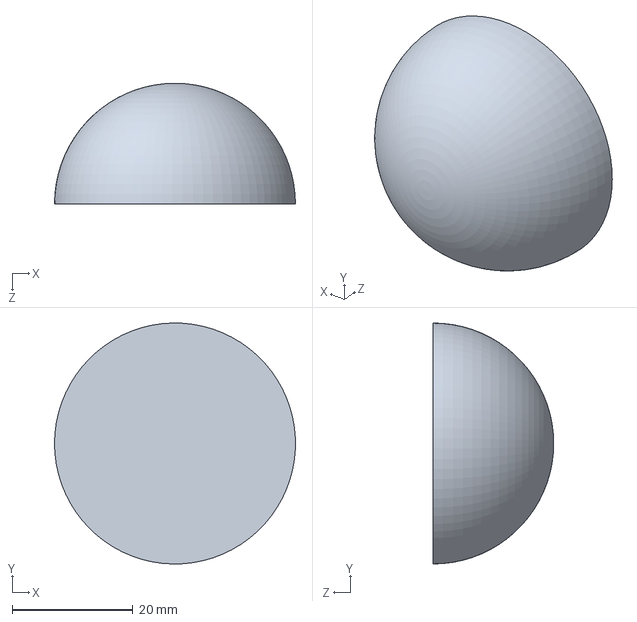
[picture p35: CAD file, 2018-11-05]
gazebo/sw2016/cir.SLDPRT
40.0 x 40.0 x 20.0 mm

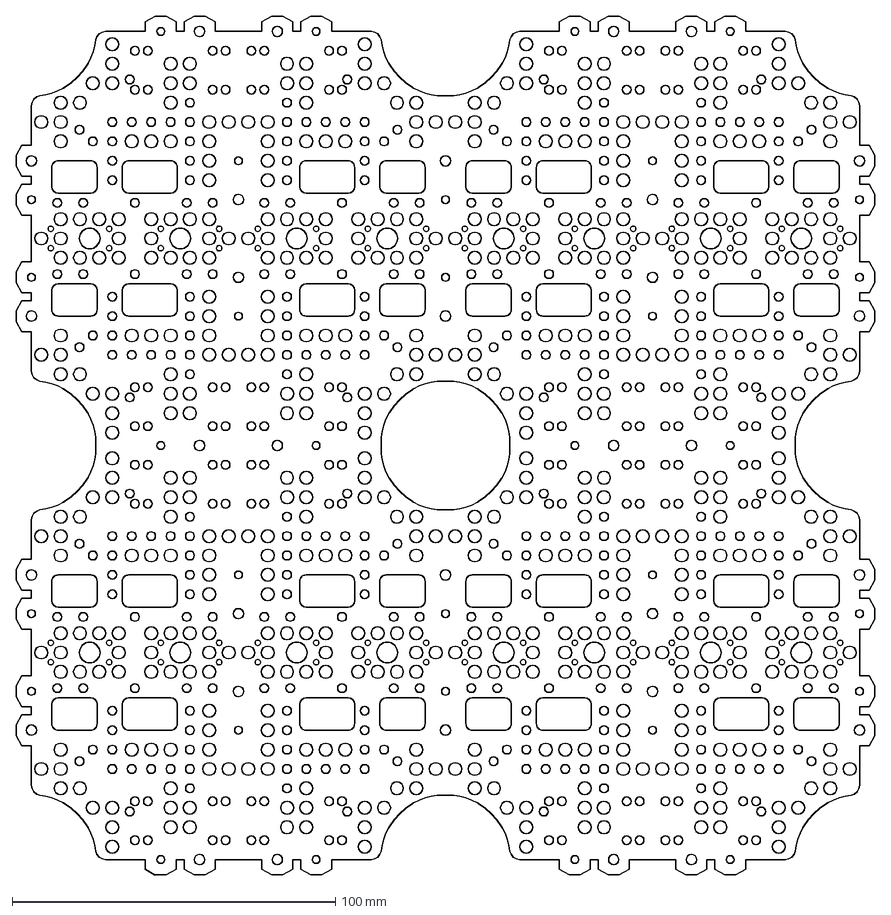
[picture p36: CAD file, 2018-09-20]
hardware/laser cut frame/waffle_plate_waffle.dxf
265.5 x 265.5 mm

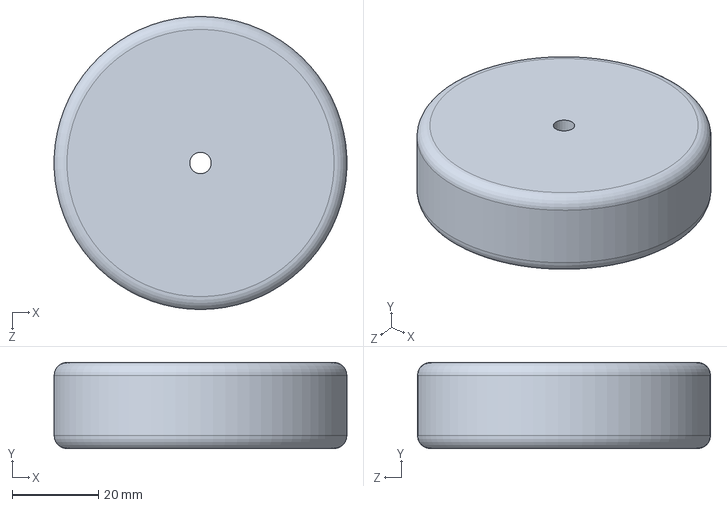
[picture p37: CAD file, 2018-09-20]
hardware/solidworks2018/wheel.SLDPRT
67.9 x 20.0 x 68.0 mm

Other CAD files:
gazebo/turtlebot3_copy/meshes/wheels/left_tire.stl
hardware/sw2016/GT2-60T-635B.SLDPRT
gazebo/minibot_simulation/meshes/l_wh.STL
gazebo/sw2016/base.SLDPRT
gazebo/sw2016/laser.SLDPRT
gazebo/sw2016/wheel.SLDPRT
hardware/laser cut frame/waffle_plate_burger.dwg
hardware/laser cut frame/waffle_plate_waffle.dwg
hardware/solidworks2018/cooper.SLDPRT
hardware/solidworks2018/waffle_plate - P-BP-A001_3D.sldprt
hardware/solidworks2018/wheel2.SLDPRT
hardware/sw2016/57motor.SLDPRT
hardware/sw2016/608RS.sldprt
hardware/sw2016/8mm_rod_150mm.SLDPRT
hardware/sw2016/KP08_1.sldprt
hardware/sw2016/MotorMount_NEMA.SLDPRT
hardware/sw2016/base.SLDPRT
hardware/sw2016/gt2_20th.SLDPRT
hardware/sw2016/gt2_gear.SLDPRT
hardware/sw2016/wheel.SLDPRT
hardware/sw2016/wheel_95mm.SLDPRT
hardware/sw2016/零件2.SLDPRT

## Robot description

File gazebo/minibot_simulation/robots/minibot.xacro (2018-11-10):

<?xml version='1.0'?>
<robot name="minibot" xmlns:xacro="http://www.ros.org/wiki/xacro">

  <xacro:include filename="$(find minibot)/robots/minibot.gazebo" />
  <xacro:include filename="$(find minibot)/robots/materials.xacro" />


  <link name="base_link">
    <inertial>
      <origin xyz="0.097204 5.5511E-17 -0.049199" rpy="0 0 0" />
      <mass value="3" />
      <inertia ixx="0.040304" ixy="4.9362E-18" ixz="0.00066866" iyy="0.041109" iyz="1.1589E-18" izz="0.07014" />
    </inertial>
    <visual>
      <origin xyz="0 0 0" rpy="0 0 0" />
      <geometry>
        <mesh filename="package://minibot/meshes/base_link.STL" />
      </geometry>
      <material name="">
        <color rgba="0.79216 0.81961 0.93333 1" />
      </material>
    </visual>
    <collision name='caster_collision'>
      <origin xyz="0 0 0" rpy="0 0 0" />
      <geometry>
        <mesh filename="package://minibot/meshes/base_link.STL" />
      </geometry>

      <surface>
        <friction>
          <ode>
            <mu>0</mu>
            <mu2>0</mu2>
            <slip1>1.0</slip1>
            <slip2>1.0</slip2>
          </ode>
        </friction>
      </surface>

    </collision>
  </link>
  <link name="l_wh">
    <inertial>
      <origin xyz="-1.3878E-17 -0.01 -2.7756E-17" rpy="0 0 0" />
      <mass value="0.3" />
      <inertia ixx="2.5261E-05" ixy="2.7793E-22" ixz="4.1451E-23" iyy="4.6188E-05" iyz="-8.0779E-25" izz="2.5438E-05" />
    </inertial>
    <visual>
      <origin xyz="0 0 0" rpy="0 0 0" />
      <geometry>
        <mesh filename="package://minibot/meshes/l_wh.STL" />
      </geometry>
      <material name="">
        <color rgba="0.28627 0.66275 0.32941 1" />
      </material>
    </visual>
    <collision>
      <origin xyz="0 0 0" rpy="0 0 0" />
      <geometry>
        <mesh filename="package://minibot/meshes/l_wh.STL" />
      </geometry>
    </collision>
  </link>
  <joint name="l_joint" type="continuous">
    <origin xyz="0 -0.153 -0.084" rpy="0 0 3.1416" />
    <parent link="base_link" />
    <child link="l_wh" />
    <axis xyz="0 1 0" />
  </joint>
  <link name="r_wh">
    <inertial>
      <origin xyz="0 0.01 2.7756E-17" rpy="0 0 0" />
      <mass value="0.3" />
      <inertia ixx="2.5261E-05" ixy="2.8014E-22" ixz="4.1451E-23" iyy="4.6188E-05" iyz="6.5376E-39" izz="2.5438E-05" />
    </inertial>
    <visual>
      <origin xyz="0 0 0" rpy="0 0 0" />
      <geometry>
        <mesh filename="package://minibot/meshes/r_wh.STL" />
      </geometry>
      <material name="">
        <color rgba="0.28627 0.66275 0.32941 1" />
      </material>
    </visual>
    <collision>
      <origin xyz="0 0 0" rpy="0 0 0" />
      <geometry>
        <mesh filename="package://minibot/meshes/r_wh.STL" />
      </geometry>
    </collision>
  </link>
  <joint name="r_joint" type="continuous">
    <origin xyz="0 0.153 -0.084" rpy="0 0 3.1416" />
    <parent link="base_link" />
    <child link="r_wh" />
    <axis xyz="0 1 0" />
  </joint>
</robot>

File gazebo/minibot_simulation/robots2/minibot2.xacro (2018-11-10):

<?xml version='1.0'?>

<robot name="myrobot" xmlns:xacro="http://www.ros.org/wiki/xacro">

  <xacro:property name="cameraSize" value="0.05"/>
  <xacro:property name="cameraMass" value="0.1"/>

  <xacro:include filename="$(find minibot)/robots2/minibot2.gazebo" />
  <xacro:include filename="$(find minibot)/robots2/materials.xacro" />
  


  <link name='chassis'>
    <pose>0 0 0.1 0 0 0</pose>

    <inertial>
      <mass value="10.0"/>
      <origin xyz="0.0 0 0.1" rpy=" 0 0 0"/>
      <inertia ixx="0.5" ixy="0" ixz="0" iyy="1.0" iyz="0" izz="0.1" />
    </inertial>

    <collision name='collision'>
      <geometry>
        <box size=".4 .2 .1"/>
      </geometry>
    </collision>

    <visual name='chassis_visual'>
      <origin xyz="0 0 0" rpy=" 0 0 0"/>
      <geometry>
        <box size=".4 .2 .1"/>
      </geometry>
    </visual>


    <collision name='caster_collision'>
      <origin xyz="-0.15 0 -0.05" rpy=" 0 0 0"/>
      <geometry>
        <sphere radius="0.05"/>
      </geometry>
      <surface>
        <friction>
          <ode>
            <mu>0</mu>
            <mu2>0</mu2>
            <slip1>1.0</slip1>
            <slip2>1.0</slip2>
          </ode>
        </friction>
      </surface>
    </collision>

    <visual name='caster_visual'>
      <origin xyz="-0.15 0 -0.05" rpy=" 0 0 0"/>
      <geometry>
        <sphere radius="0.05"/>
      </geometry>
    </visual>
  </link>


  <link name="left_wheel">
    <!--origin xyz="0.1 0.13 0.1" rpy="0 1.5707 1.5707"/-->
    <collision name="collision">
      <origin xyz="0 0 0" rpy="0 1.5707 1.5707"/>
      <geometry>
        <cylinder radius="0.1" length="0.05"/>
      </geometry>
    </collision>
    <visual name="left_wheel_visual">
      <origin xyz="0 0 0" rpy="0 1.5707 1.5707"/>
      <geometry>
        <cylinder radius="0.1" length="0.05"/>
      </geometry>
    </visual>
    <inertial>
      <origin xyz="0 0 0" rpy="0 1.5707 1.5707"/>
      <mass value="5"/>
      <cylinder_inertia m="5" r="0.1" h="0.05"/>
      <inertia ixx="1.0" ixy="0.0" ixz="0.0" iyy="1.0" iyz="0.0" izz="1.0"/>
    </inertial>
  </link>

  <link name="right_wheel">
    <!--origin xyz="0.1 -0.13 0.1" rpy="0 1.5707 1.5707"/-->
    <collision name="collision">
      <origin xyz="0 0 0" rpy="0 1.5707 1.5707"/>
      <geometry>
        <cylinder radius="0.1" length="0.05"/>
      </geometry>
    </collision>
    <visual name="right_wheel_visual">
      <origin xyz="0 0 0" rpy="0 1.5707 1.5707"/>
      <geometry>
        <cylinder radius="0.1" length="0.05"/>
      </geometry>
    </visual>
    <inertial>
      <origin xyz="0 0 0" rpy="0 1.5707 1.5707"/>
      <mass value="5"/>
      <cylinder_inertia m="5" r="0.1" h="0.05"/>
      <inertia ixx="1.0" ixy="0.0" ixz="0.0" iyy="1.0" iyz="0.0" izz="1.0"/>
    </inertial>
  </link>


  <joint type="continuous" name="left_wheel_hinge">
    <origin xyz="0.1 0.15 0" rpy="0 0 0"/>
    <!--origin xyz="0.1 0.13 0" rpy="0 1.5707 1.5707"/-->
    <child link="left_wheel"/>
    <parent link="chassis"/>
    <axis xyz="0 1 0" rpy="0 0 0"/>
    <limit effort="100" velocity="100"/>
    <joint_properties damping="0.0" friction="0.0"/>
  </joint>

  <joint type="continuous" name="right_wheel_hinge">
    <origin xyz="0.1 -0.15 0" rpy="0 0 0"/>
    <!--origin xyz="0.1 -0.13 0" rpy="0 1.5707 1.5707"/-->
    <child link="right_wheel"/>
    <parent link="chassis"/>
    <axis xyz="0 1 0" rpy="0 0 0"/>
    <limit effort="100" velocity="100"/>
    <joint_properties damping="0.0" friction="0.0"/>
  </joint>


  <link name="camera">
    <collision>
      <origin xyz="0 0 0" rpy="0 0 0"/>
      <geometry>
        <box size="${cameraSize} ${cameraSize} ${cameraSize}"/>
      </geometry>
    </collision>

    <visual>
      <origin xyz="0 0 0" rpy="0 0 0"/>
      <geometry>
        <box size="${cameraSize} ${cameraSize} ${cameraSize}"/>
      </geometry>
      <material name="green"/>
    </visual>

    <inertial>
      <mass value="${cameraMass}" />
      <origin xyz="0 0 0" rpy="0 0 0"/>
      <box_inertia m="${cameraMass}" x="${cameraSize}" y="${cameraSize}" z="${cameraSize}" />
      <inertia ixx="1e-6" ixy="0" ixz="0" iyy="1e-6" iyz="0" izz="1e-6" />
    </inertial>
  </link>

  <joint name="camera_joint" type="fixed">
    <axis xyz="0 1 0" />
    <origin xyz=".2 0 0" rpy="0 0 0"/>
    <parent link="chassis"/>
    <child link="camera"/>
  </joint>


  <joint name="hokuyo_joint" type="fixed">
    <axis xyz="0 1 0" />
    <origin xyz=".15 0 .1" rpy="0 0 0"/>
    <parent link="chassis"/>
    <child link="hokuyo"/>
  </joint>

  <!-- Hokuyo Laser -->
  <link name="hokuyo">
    <collision>
      <origin xyz="0 0 0" rpy="0 0 0"/>
      <geometry>
    <box size="0.1 0.1 0.1"/>
      </geometry>
    </collision>

    <visual>
      <origin xyz="0 0 0" rpy="0 0 0"/>
      <geometry>
        <mesh filename="package://minibot/meshes/hokuyo.dae"/>
      </geometry>
    </visual>

    <inertial>
      <mass value="1e-5" />
      <origin xyz="0 0 0" rpy="0 0 0"/>
      <inertia ixx="1e-6" ixy="0" ixz="0" iyy="1e-6" iyz="0" izz="1e-6" />
    </inertial>
  </link>


</robot>

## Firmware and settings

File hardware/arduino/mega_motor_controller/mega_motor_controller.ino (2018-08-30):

/**
 *  Name : mega_motor_controller
 *
 *  Author : Tony Guo
 *  
 *  Country : Taiwan
 *
 *  Date : 15 Aug, 2018 
 */



#include "PID.h"
#include "shift_in.h"
#include "serial_print_speed.h"
#include "serial_read.h"


//left
#define motorA 2
#define motorA_ 3
//#define Freq_l 11
#define DL 6
#define pwmA 12

//right
#define motorB 4
#define motorB_ 5
//#define Freq_r 12
#define DR 7
#define pwmB 11


//motor defination
#define PPR  374.22
#define readRate 100 //ms  ,motor encoder read rate

//setup serial print rate
#define printRate 100 //ms


float motorSendL = 0;
float motorSendR = 0;
float WL_send = 0;
float WR_send = 0;
float serialRead_L;
float serialRead_R;

int LatchPin = 8;
int DataPin = 10;
int ClockPin = 9;
int ResetPin = 13;

void Run(int n,int _n,int moto,int dir,int spe);

void setup() {
  //freq_init(latchPin,dataPin,clockPin,DL,DR,readRate);
  serialReadInit();
  PIDinit(5,5,3,0);//set KP,PI,KD here & pid Enable ,if disable,output will be input directly
  freq_init(LatchPin,DataPin,ClockPin,ResetPin,DR,DL,100);//LatchPin,DataPin,ClockPin,ResetPin,DL,DR,Rate

  pinMode(DR,INPUT);
  pinMode(DL,INPUT);
  pinMode(motorA,OUTPUT);
  pinMode(motorA_,OUTPUT);
  pinMode(motorB,OUTPUT);
  pinMode(motorB_,OUTPUT);
  while (!Serial); 
}

void loop() {
  
  WL_send = freq_read(0,PPR);//(rad/s)  //0:left
  WR_send = freq_read(1,PPR);           //1:right

  //Serial.print(WL_send);
  //Serial.print("   ");
  //Serial.println(WR_send);

  printSpeed(WL_send,WR_send,printRate);

  serialRead_L = (float)serialRead(0)/100.0; //0:left
  serialRead_R = (float)serialRead(1)/100.0; //1:right

  //Serial.println(serialRead_L);
  //Serial.println(serialRead_R);

  motorSendL = (float)PIDstep(1,serialRead_L,WL_send);
  motorSendR = (float)PIDstep(0,serialRead_R,WR_send);
  //motorSendR =-100.0;

  //Serial.println(motorSendL);
  //Serial.println(motorSendR);

  //if(motorSendR<0)Serial.println(motorSendL);
  //Serial.println(motorSendR);
  
  Run(motorA,motorA_,pwmA,((int)motorSendL>0)?(0):(1),abs(motorSendL));
  Run(motorB,motorB_,pwmB,((int)motorSendR>0)?(1):(0),abs(motorSendR));

  //Serial.println(" ");
  //Serial.println(motorSendL);
  
  //Run(motorA,motorA_,pwmA,0,100); //(pin)pwmA control left motor
  //Run(motorB,motorB_,pwmB,1,100); //(pin)pwmB control right motor
  //digitalWrite(motorB,HIGH);
  
}


void Run(int n,int _n,int moto,int dir,int spe){
  if(dir){
    digitalWrite(n,HIGH);
    digitalWrite(_n,LOW);
    analogWrite(moto,spe);
  }else{
    digitalWrite(n,LOW);
    digitalWrite(_n,HIGH);
    analogWrite(moto,spe); 
  }
  //(dir)?(analogWrite(n,spe),analogWrite(_n,0)):(analogWrite(_n,spe),analogWrite(n,0));
}

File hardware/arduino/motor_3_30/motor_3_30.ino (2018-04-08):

#define motorB 5
#define motorB_ 6 //left
#define motorA 9
#define motorA_ 10 //right

#define FL 2 //left
#define FR 3 //right
#define DL 12 //left
#define DR 11 //right

volatile uint8_t STEP_R = 0; 
volatile uint8_t STEP_L = 0;
volatile float  WR = 0;
volatile float  WL = 0;  
volatile uint16_t Time = 0; 
String DDR,DDL; 

///////////////////////////////////////////////////////////////////////////////
// Interrupt func
void Freq_int_L(){STEP_L++;}
void Freq_int_R(){STEP_R++;}


void Run(int n,int _n,int dir,int spe);
int Read(int sel);//sel=1 >>left  sel=0 >>right



void setup() {
  pinMode(FR,INPUT_PULLUP);
  pinMode(FL,INPUT_PULLUP);
  pinMode(DR,INPUT);
  pinMode(DL,INPUT);
  attachInterrupt(digitalPinToInterrupt(FL),Freq_int_L,RISING);
  attachInterrupt(digitalPinToInterrupt(FR),Freq_int_R,RISING);
  pinMode(motorA,OUTPUT);
  pinMode(motorA_,OUTPUT);
  pinMode(motorB,OUTPUT);
  pinMode(motorB_,OUTPUT);
  Serial.begin(115200);
  Serial.setTimeout(20);
}

void loop() {
  
  Run(motorA,motorA_,(Read(1)>0)?(1):(0),abs(Read(1)));
  Run(motorB,motorB_,(Read(0)>0)?(1):(0),abs(Read(0)));

  if(millis()-Time>=100){
    WR = ((float)STEP_R/374.22)*10.0; //rad/s
    WL = ((float)STEP_L/374.22)*10.0; //rad/s
    STEP_R = 0;
    STEP_L = 0;
    int IWR = WR*100;
    int IWL = WL*100;
    String SWR = (String)IWR;
    String SWL = (String)IWL;
    while(SWR.length()<3){SWR = '0'+SWR;}
    while(SWL.length()<3){SWL = '0'+SWL;}
    (!digitalRead(DR))?(SWR ='0'+SWR):(SWR ='1'+SWR);
    (digitalRead(DL))?(SWL ='0'+SWL):(SWL ='1'+SWL);

    Serial.println(SWR+SWL);
//    Serial.print("VL=");
//    Serial.print(VL);
//    Serial.print("  VR=");
//    Serial.println(VR);
    Time = millis();
  }
}

int Read(int sel){
    static int speed_l=0;  
    static int speed_r=0; 
    static char buf; 
    static int RW=0;
    static char Databuf[8]={0};     // 用來儲存收進來的 data byte  
    static int addr=0;
    if (Serial.available() > 0) {
    buf = Serial.read(); 
    switch (buf){
      case '(':
        RW=1;
        break;
      case ')':
        RW=0;
        if(((int)Databuf[0]-48)==0){
          speed_r=((int)Databuf[1]-48)*100+((int)Databuf[2]-48)*10+((int)Databuf[3]-48)*1;
        }else{
          speed_r=(((int)Databuf[1]-48)*100+((int)Databuf[2]-48)*10+((int)Databuf[3]-48)*1)*(-1);
        }
        if(((int)Databuf[4]-48)==0){
          speed_l=((int)Databuf[5]-48)*100+((int)Databuf[6]-48)*10+((int)Databuf[7]-48)*1;
        }else{
          speed_l=(((int)Databuf[5]-48)*100+((int)Databuf[6]-48)*10+((int)Databuf[7]-48)*1)*(-1);
        }
        addr=0;
        break;
      case '!':
          for(int i=0;i<=7;i++){
            Serial.print("Databuf ") ;
            Serial.print(i) ;
            Serial.print("= ") ;
            Serial.println(Databuf[i]); 
          }

          Serial.println(speed_l);
          Serial.println(speed_r);
          addr=0;
        break;
      default:  
        if(RW==1){
          Databuf[addr]=buf;
          addr++;  
        }
        break;
    }
  }
  if(sel){
    return speed_l;
  }else{
    return speed_r;
  }
}

void Run(int n,int _n,int dir,int spe){
  (dir)?(analogWrite(n,spe),analogWrite(_n,0)):(analogWrite(_n,spe),analogWrite(n,0));
}

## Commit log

2018-08-15 pcb update
2018-09-20 lemon minibot sw
    [layer.SLDASM, minibot.SLDASM, waffle_plate - P-BP-A001_3D.sldprt]
2018-09-20 upload laser cut file
    [waffle_plate_burger.dwg, waffle_plate_burger.dxf, waffle_plate_waffle.dwg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]
2018-09-20 upload stm32 controller
2018-09-20 edit launch
    [ball.STL, l_whee;.STL, minibot.URDF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]
2018-09-21 update gazebo
    [l_whee.STL, minibot.SLDASM, minibot.URDF]
2018-09-21 sw update
    [minibot.SLDASM]
2018-09-21 gazebo launch
    [l_whee.STL, minibot.URDF]
2018-11-05 gazebo test
    [ball.STL, base.SLDPRT, base_link.STL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]
2018-11-05 sw save
    [minibot.SLDASM]
2018-11-10 success gazebo
    [common_properties.xacro, lds.stl, left_tire.stl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]
2018-11-13 up gazebo info & reme
    [turtlebot3_waffle_pi.gazebo.xacro, turtlebot3_waffle_pi.urdf.xacro]
2018-11-13 up simulation
    [base_link.STL, l_wh.STL, materials.xacro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]
2018-11-13 fix dir & up reme
    [common_properties.xacro, lds.stl, left_tire.stl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]
2018-11-14 add rf2o to sim
    [turtlebot3_waffle_pi.gazebo.xacro]
2018-11-16 test ok, smach next
    [turtlebot3_waffle_pi.gazebo.xacro]
2018-11-21 up dae
    [ar.urdf]
2018-11-22 ar in gazebo success
    [ar.urdf, turtlebot3_waffle_pi.gazebo.xacro]
2018-11-22 angle fix
    [turtlebot3_waffle_pi.gazebo.xacro, turtlebot3_waffle_pi.urdf.xacro]
2019-01-13 up new car
    [57motor.SLDPRT, 608RS.sldprt, 8mm_rod_150mm.SLDPRT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]
